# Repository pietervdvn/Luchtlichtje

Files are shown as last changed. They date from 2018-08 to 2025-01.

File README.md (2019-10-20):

# Luchtlichtje

Source code and hardware spec of the ESP8266 driven Air Quality Indicator "Luchtlichtje" (Dutch for 'air light')

A small ESP/Arduino Project, showing lights indicating the air quality, based on data from luftdaten.info

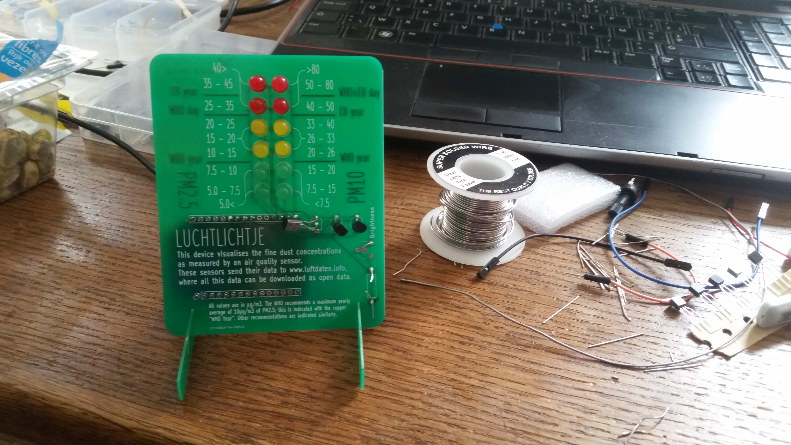
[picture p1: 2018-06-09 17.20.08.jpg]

Moving Pic

## API

Get your sensor data at http://api.luftdaten.info/v1/sensor/7245/

## Bill of Materials

- A Luchtlichtje PCB
- 4 LEDS of each colour (RED, YELLOW, GREEN) of 5mm (or some other colours)
- 3 resistors of around 10ohm (use higher such as 220ohm for less brightness)
- 1 photoresistor of a pretty high resistance, in combination with a 1Mohm resistor*

*If you don't like the brightness settings or have a different photoresistor, you can change the code to have other settings*

## Flashing a Luchtlichtje

- Install platformio
- Open the console
- cd to the desired directory (v0.2/firmware)
- `sudo platformio run --target upload`
- Use `platformio run --target monitor` to see what is happening

## Assembly instructions

- Start with placing the resistors. The resistor 'R1 Different'-resistor (bottom right) takes the 1-mega-ohm resistor
- The other three have 10-ohm resistors (upper and left side).
- Next, place the leds. Be carefull, they have to be oriented correctly: the flattened sides go in the middle. Green leds down, red leds up - just like traffic lights. Solder them neatly and straight.
- Place and solder the header pins on the backside of the board.
- Flash the software on the nodemcu and place it on the backside (see above).
- Gently break the board along the cutlines on the right. If they don't come off, use a knife on the back side of the board.
- These small rectangular break-off pieces can be slided in the main board, to place it on your desk.
- The break-off parts easily fall of the board when lifted. To prevent this, place a piece of wire through the holes in the break-off part and the main board.
- All done! Enjoy your Luchtlichtje.

## Troubleshooting

When booting, the board will test all leds blinking from up to down.
If a led does not blink, check the soldering.
If more then the desired leds burn, some LEDS are soldered in the wrong direction.

If the orange leds start blinking one after another; the board is connecting to the wifi. This will always happen for a few seconds when booting.

If the reds leds are blinking, either luftdaten or your sensor is down. 

## Versions

The first version (v1.0) is dated 2018-05-15
The second version (v2.0) is dated 2018-08-24. Changes are: removal of unused transistors, addition of a brightness sensor, fancier placement of resistors.

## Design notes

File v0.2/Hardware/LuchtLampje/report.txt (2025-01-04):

Info: Backing up file '/home/pietervdvn/git/Luchtlichtje/v0.2/Hardware/LuchtLampje/sym-lib-table' to '/home/pietervdvn/git/Luchtlichtje/v0.2/Hardware/LuchtLampje/rescue-backup/sym-lib-table-2025-01-04-02-21-57'.
Info: Backing up file '/home/pietervdvn/git/Luchtlichtje/v0.2/Hardware/LuchtLampje/LuchtLampje.sch' to '/home/pietervdvn/git/Luchtlichtje/v0.2/Hardware/LuchtLampje/rescue-backup/LuchtLampje-2025-01-04-02-21-57.sch'.
Info: Backing up file '/home/pietervdvn/git/Luchtlichtje/v0.2/Hardware/LuchtLampje/LuchtLampje.kicad_pro' to '/home/pietervdvn/git/Luchtlichtje/v0.2/Hardware/LuchtLampje/rescue-backup/LuchtLampje-2025-01-04-02-21-57.kicad_pro'.
Info: Backing up file '/home/pietervdvn/git/Luchtlichtje/v0.2/Hardware/LuchtLampje/LuchtLampje-cache.lib' to '/home/pietervdvn/git/Luchtlichtje/v0.2/Hardware/LuchtLampje/rescue-backup/LuchtLampje-cache-2025-01-04-02-21-57.lib'.
Info: Backing up file '/home/pietervdvn/git/Luchtlichtje/v0.2/Hardware/LuchtLampje/LuchtLampje-rescue.lib' to '/home/pietervdvn/git/Luchtlichtje/v0.2/Hardware/LuchtLampje/rescue-backup/LuchtLampje-rescue-2025-01-04-02-21-57.lib'.
Info: Backing up file '/home/pietervdvn/git/Luchtlichtje/v0.2/Hardware/LuchtLampje/LuchtLampje-rescue.dcm' to '/home/pietervdvn/git/Luchtlichtje/v0.2/Hardware/LuchtLampje/rescue-backup/LuchtLampje-rescue-2025-01-04-02-21-57.dcm'.
Info: Adding library 'LuchtLampje-rescue', file '${KIPRJMOD}/LuchtLampje-rescue.lib' to project symbol library table.
Symbol LED mapped to symbol library 'LuchtLampje-rescue'.
Symbol LED mapped to symbol library 'LuchtLampje-rescue'.
Symbol LED mapped to symbol library 'LuchtLampje-rescue'.
Symbol LED mapped to symbol library 'LuchtLampje-rescue'.
Symbol LED mapped to symbol library 'LuchtLampje-rescue'.
Symbol R mapped to symbol library 'LuchtLampje-rescue'.
Symbol LED mapped to symbol library 'LuchtLampje-rescue'.
Symbol LED mapped to symbol library 'LuchtLampje-rescue'.
Symbol R mapped to symbol library 'LuchtLampje-rescue'.
Symbol R mapped to symbol library 'LuchtLampje-rescue'.
Symbol LED mapped to symbol library 'LuchtLampje-rescue'.
Symbol LED mapped to symbol library 'LuchtLampje-rescue'.
Symbol LED mapped to symbol library 'LuchtLampje-rescue'.
Symbol LED mapped to symbol library 'LuchtLampje-rescue'.
Symbol LED mapped to symbol library 'LuchtLampje-rescue'.
Symbol CONN_01X15 mapped to symbol library 'LuchtLampje-rescue'.
Symbol CONN_01X15 mapped to symbol library 'LuchtLampje-rescue'.
Symbol R mapped to symbol library 'LuchtLampje-rescue'.
Symbol R_PHOTO mapped to symbol library 'LuchtLampje-rescue'.
Info: Symbol library table mapping complete!
Info: Created project symbol library table.

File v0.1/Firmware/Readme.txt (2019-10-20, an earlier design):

The firmware for version 1.0 has been merged with the firmware for 2.0.

The major difference between both is the addition of brightness-sensor. For a v1.0 board, disable it in the firmware by setting the USE_BRIGHTNESS -macro to false

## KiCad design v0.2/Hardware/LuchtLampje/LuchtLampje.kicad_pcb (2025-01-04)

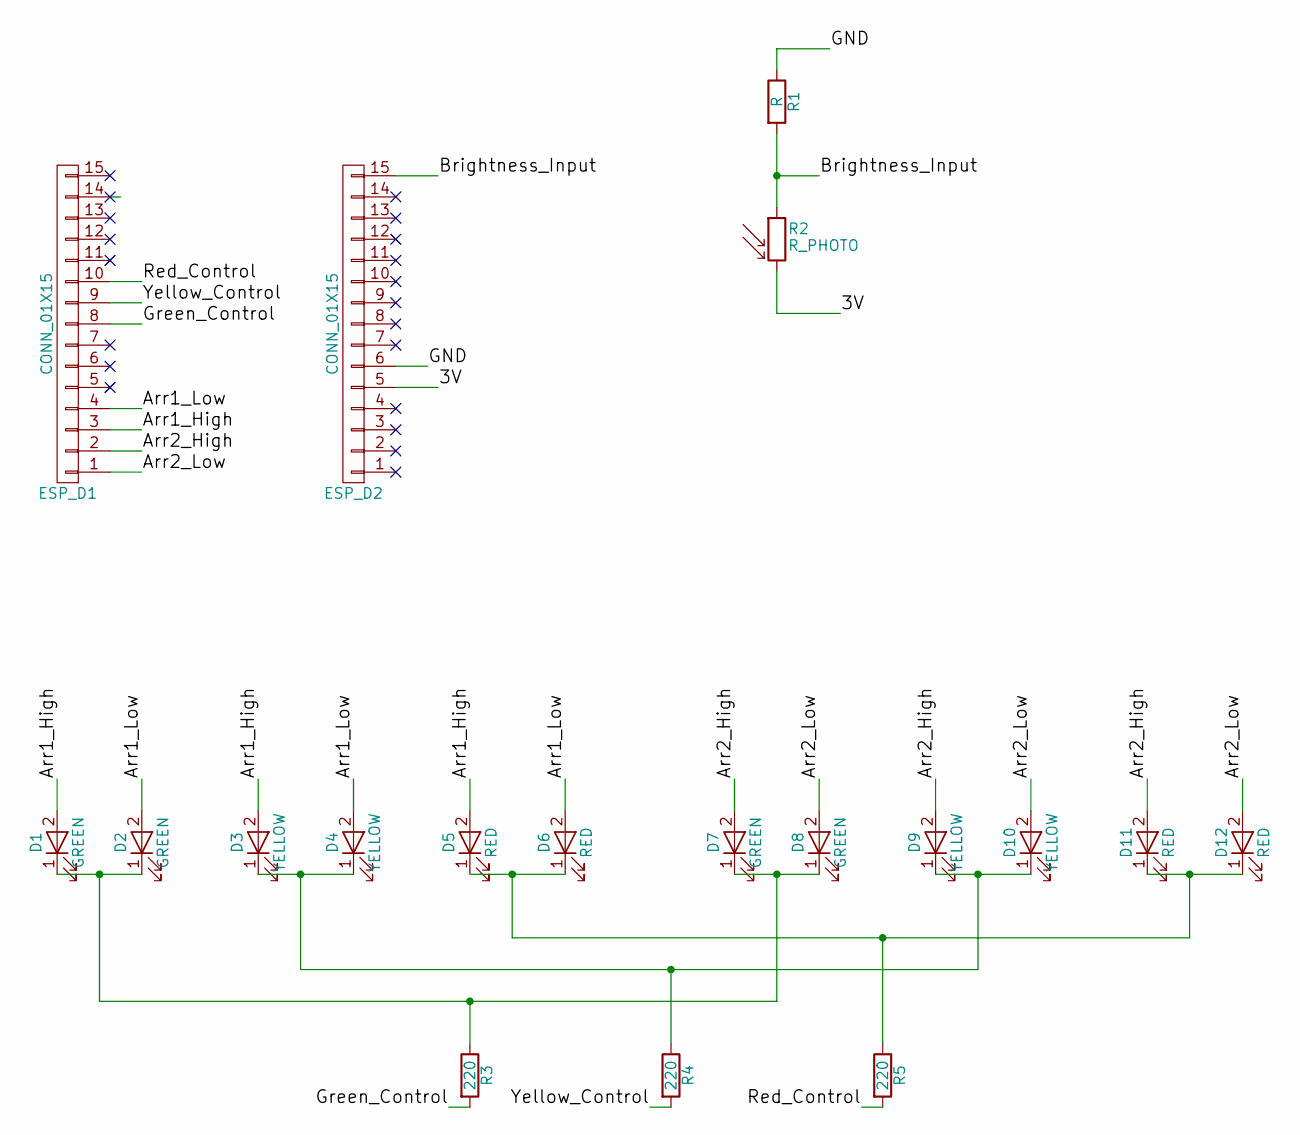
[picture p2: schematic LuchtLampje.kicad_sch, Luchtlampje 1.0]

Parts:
D1, D2, D7, D8: GREEN; LED_D5.0mm
D3, D4, D9, D10: YELLOW; LED_D5.0mm
D5, D6, D11, D12: RED; LED_D5.0mm
ESP_D1, ESP_D2: CONN_01X15; Socket_Strip_Straight_1x15_Pitch2.54mm
R1: R; R_Axial_DIN0411_L9.9mm_D3.6mm_P12.70mm_Horizontal
R2: R_PHOTO; R1
R3, R4, R5: 220; R_Axial_DIN0411_L9.9mm_D3.6mm_P12.70mm_Horizontal

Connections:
/3V: ESP_D2.5, R2.2
/Arr1_High: D1.2 (A), D3.2 (A), D5.2 (A), ESP_D1.3
/Arr1_Low: D2.2 (A), D4.2 (A), D6.2 (A), ESP_D1.4
/Arr2_High: D7.2 (A), D9.2 (A), D11.2 (A), ESP_D1.2
/Arr2_Low: D8.2 (A), D10.2 (A), D12.2 (A), ESP_D1.1
/Brightness_Input: ESP_D2.15, R1.2, R2.1
/GND: ESP_D2.6, R1.1
/Green_Control: ESP_D1.8, R3.2
/Red_Control: ESP_D1.10, R5.2
/Yellow_Control: ESP_D1.9, R4.2
unnamed: D1.1 (K), D2.1 (K), D7.1 (K), D8.1 (K), R3.1
unnamed: D3.1 (K), D4.1 (K), D9.1 (K), D10.1 (K), R4.1
unnamed: D5.1 (K), D6.1 (K), D11.1 (K), D12.1 (K), R5.1

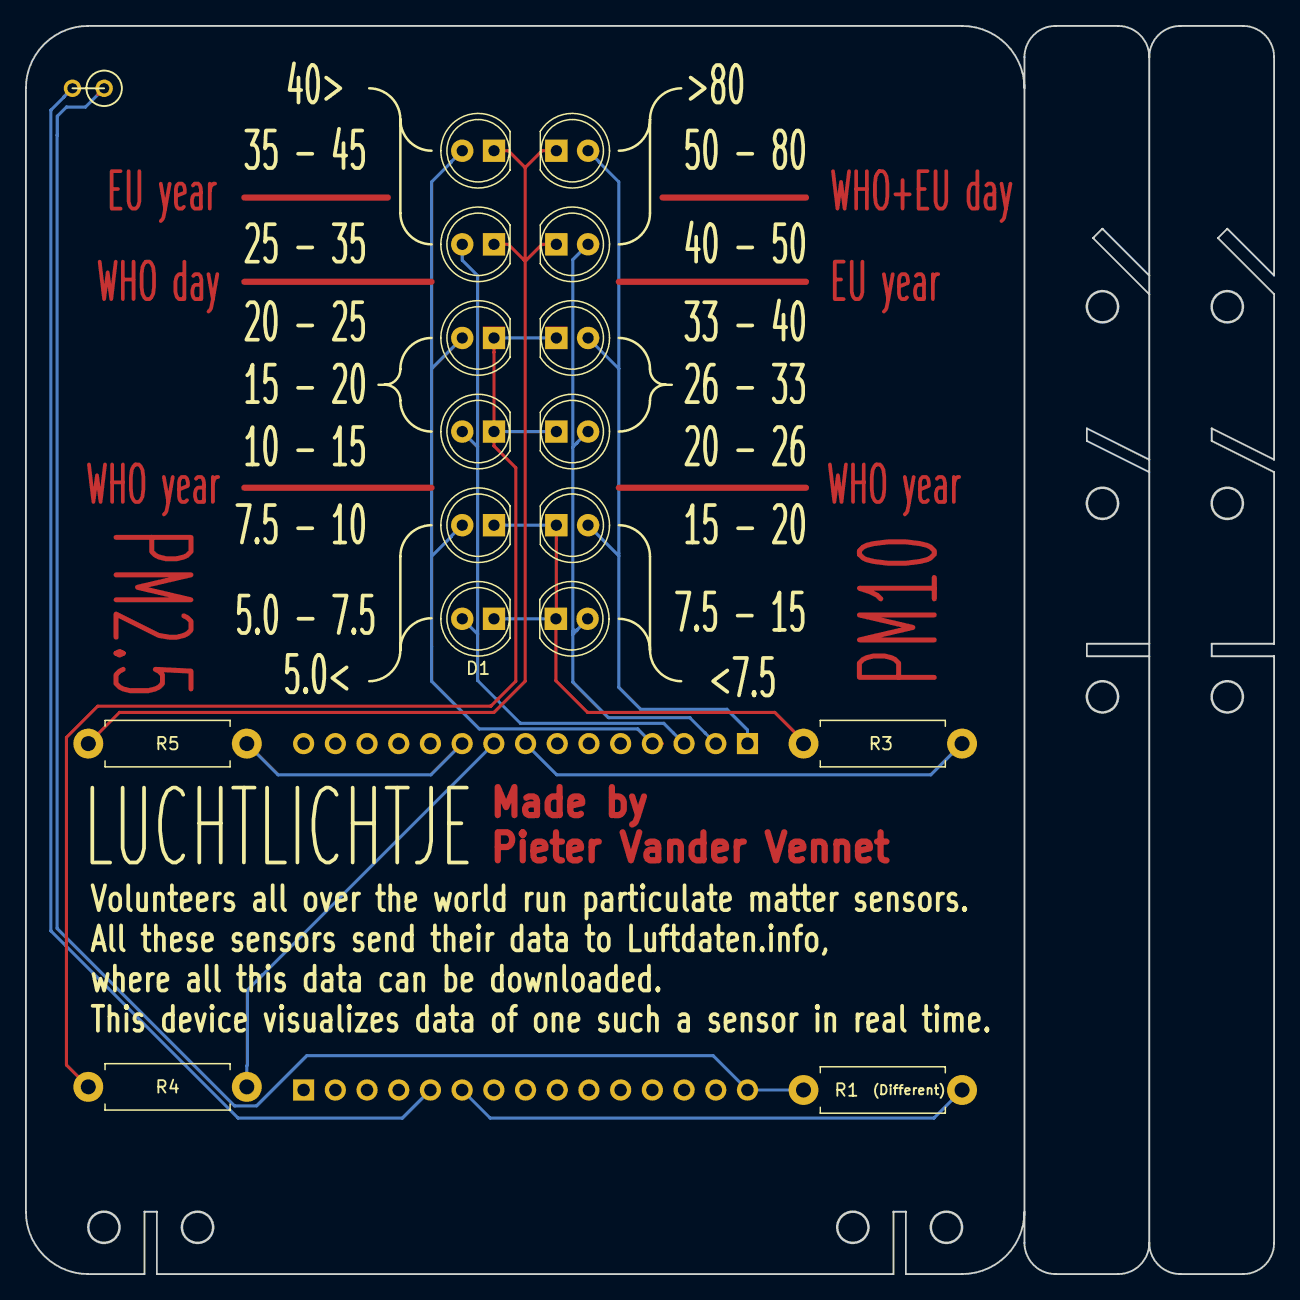
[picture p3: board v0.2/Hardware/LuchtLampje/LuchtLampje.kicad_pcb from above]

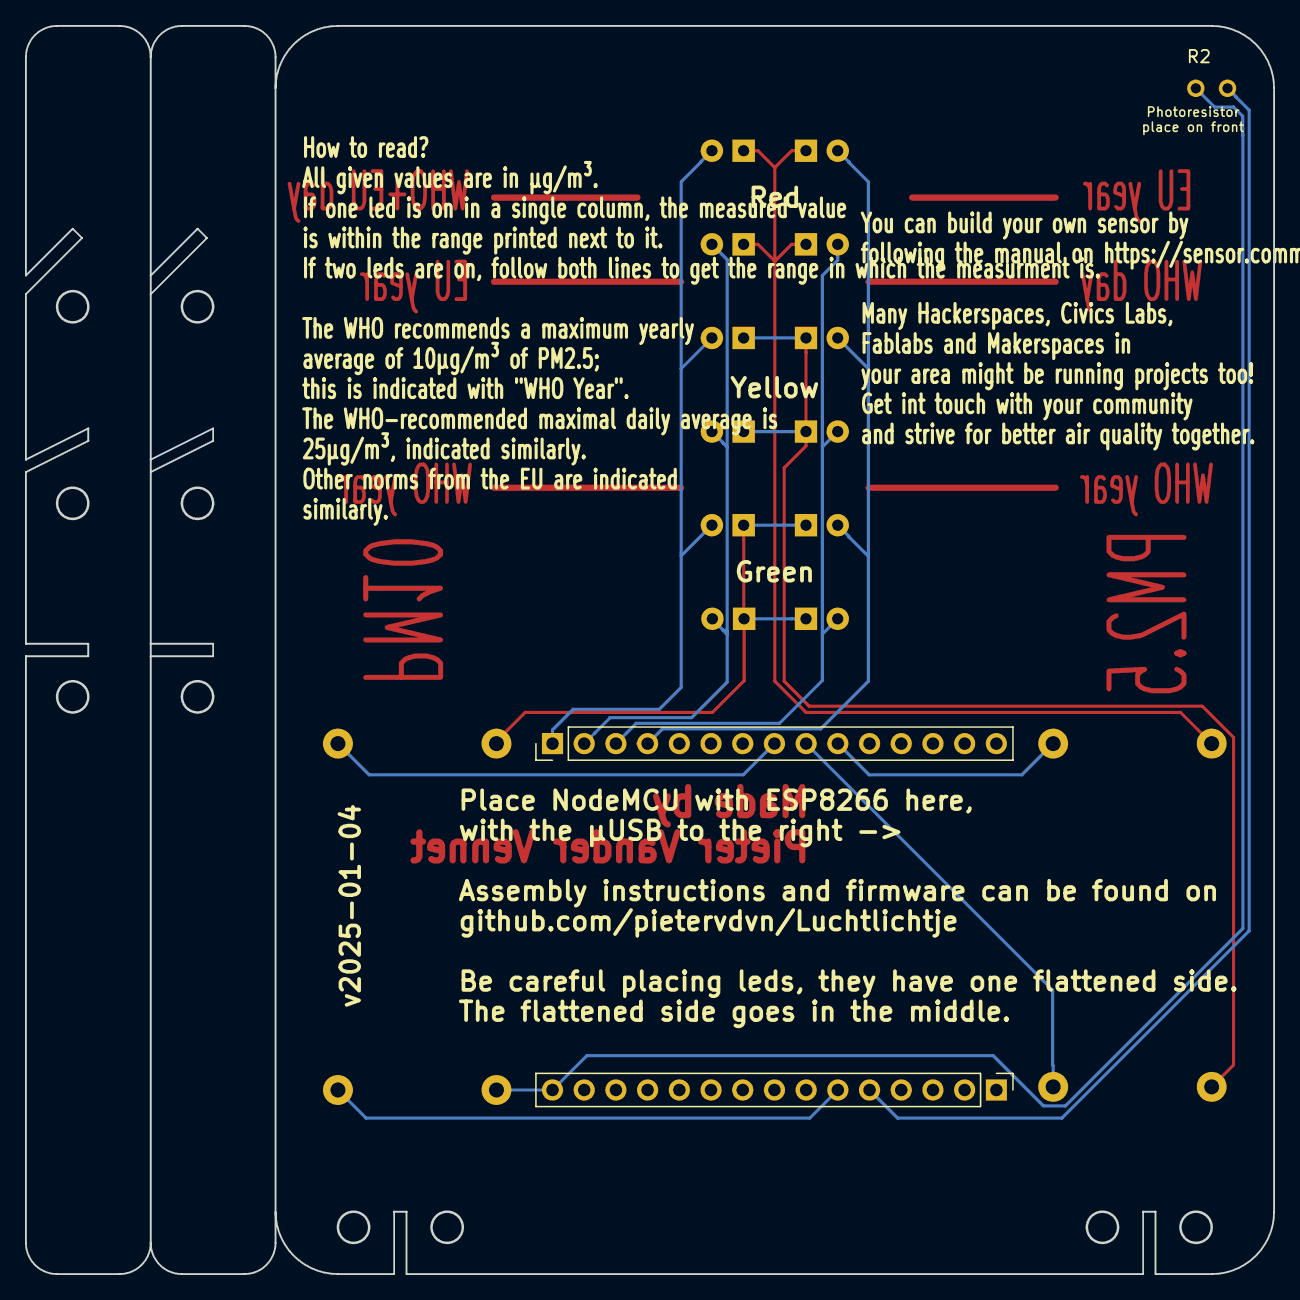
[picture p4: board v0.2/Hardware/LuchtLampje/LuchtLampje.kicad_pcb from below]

Board: 2 copper layers, 100.0 x 100.0 mm, 19 parts (2 on the bottom side), 13 nets.

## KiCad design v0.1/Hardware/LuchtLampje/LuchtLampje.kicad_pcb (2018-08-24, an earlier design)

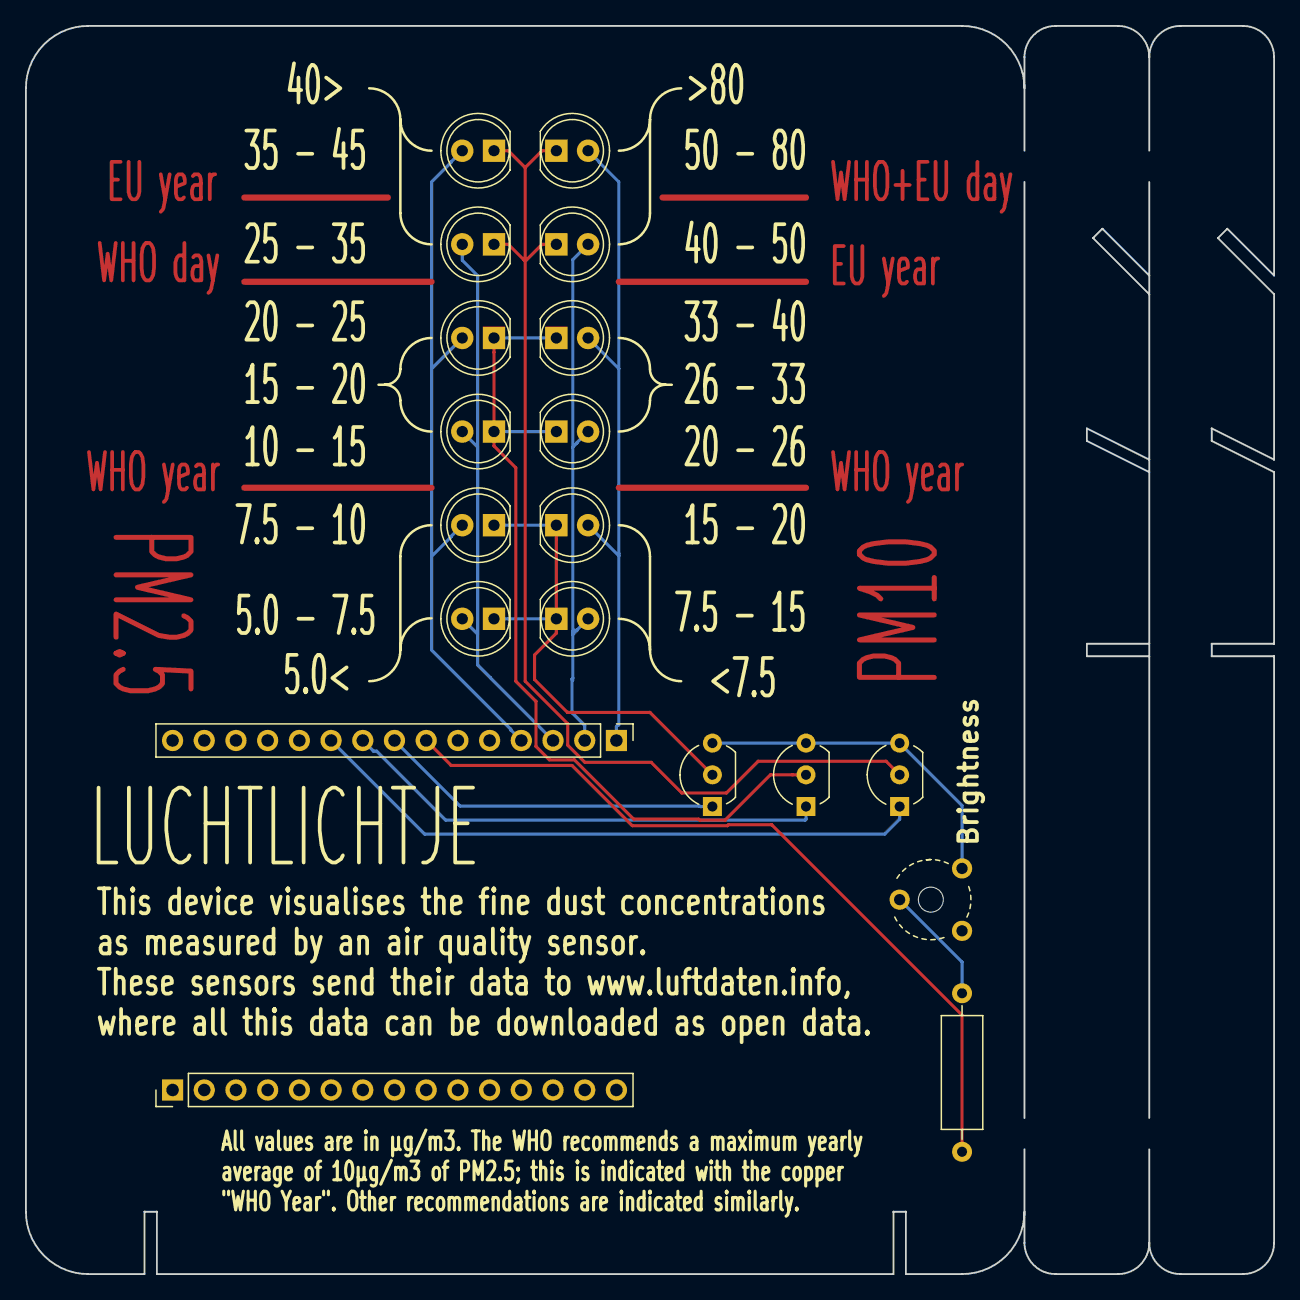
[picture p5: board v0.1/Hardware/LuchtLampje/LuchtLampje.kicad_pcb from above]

Board: 2 copper layers, 100.0 x 100.0 mm, 19 parts (0 on the bottom side), 13 nets.

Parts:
D2, D7, D8: GREEN; LED_D5.0mm
D3, D4, D9, D10: YELLOW; LED_D5.0mm
D5, D6, D11, D12: RED; LED_D5.0mm
ESP_D1, ESP_D2: CONN_01X15; Socket_Strip_Straight_1x15_Pitch2.54mm
Green: GREEN; LED_D5.0mm
Q1, Q2, Q3: NPN_Green; TO-92_Inline_Wide
R1: 1K; R_Axial_DIN0309_L9.0mm_D3.2mm_P12.70mm_Horizontal
RV1: POT 10K; Potentiometer_Trimmer_Piher_PT-6v_Horizontal_MountLS

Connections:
/Arr1_High: D3.2, D5.2, ESP_D1.3, Green.2
/Arr1_Low: D2.2, D4.2, D6.2, ESP_D1.4
/Arr2_High: D7.2, D9.2, D11.2, ESP_D1.2
/Arr2_Low: D8.2, D10.2, D12.2, ESP_D1.1
/GND: ESP_D1.7, R1.2
/Green_Control: ESP_D1.8, Q1.1
/Red_Control: ESP_D1.10, Q3.1
/Yellow_Control: ESP_D1.9, Q2.1
unnamed: D2.1, D7.1, D8.1, Green.1, Q1.2
unnamed: D3.1, D4.1, D9.1, D10.1, Q2.2
unnamed: D5.1, D6.1, D11.1, D12.1, Q3.2
unnamed: Q1.3, Q2.3, Q3.3, RV1.1
unnamed: R1.1, RV1.2

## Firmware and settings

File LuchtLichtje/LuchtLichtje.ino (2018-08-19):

#include <ArduinoJson.h>
#include <ESP8266WiFi.h>
#include <ESP8266WiFiMulti.h>
#include <ESP8266HTTPClient.h>
#include <Arduino.h>

/** 
 * Kindoff working working 2018-08-19
 * Use Arduino IDE
 * ESP8266 by ESP8266 Community v. 2.3.0
 * Board: NodeMCU (12E)
 * CPU Freq: 80Mhz
 * Flash size: 4M (3M SPiffs)
 * Upload speed: 115200
 */

// WIFI DETAILS


// TYPE YOUR WIFI SSID HERE:
#define WIFIAP "fri3d-legacy"
// TYPE YOUR WIFI PASSWORD HERE
#define WIFIPASS "fri3dcamp"
// SEARCH A SENSOR ON luftdaten.info
// CLICK IT
// LOOK FOR SENSOR ID IN THE TABLE APPEARING RIGHT
// CHANGE IT ON THE END (do not remove the trailing slash)
#define SENSOR "http://api.luftdaten.info/v1/sensor/12988/"





// Time between two updates, in minutes
#define UPDATE_TIMEOUT 15
// Time in seconds between retries when failed. Should be a multiple of 4
#define RETRY_TIMEOUT 12

// ---------------------------------------- PIN DEFINTIONS FOR LEDS ------------------------------------------

#define RIGHTH D0
#define RIGHTL D1

#define LEFTH D3
#define LEFTL D2

#define GREEN D5
#define YELLOW D6
#define RED D7

#define LEFT 0
#define RIGHT 1

#define posPinL 4
// should be HIGH to work
int posPins[posPinL] = {LEFTH, LEFTL, RIGHTH, RIGHTL}; 
#define negPinL 3
// should be low to work
int negPins[negPinL] = {RED, YELLOW, GREEN}; 
// ---------------------- WIFI STUFF

ESP8266WiFiMulti WiFiMulti;

// -------------------------- Status tracking

#define CONNECTING 0
#define UP_TO_DATE 1

#define NOT_CONNECTED 2
#define HTTP_ERR 3
#define PARSE_ERR 4

// Color encodings
#define EXTREMELY_GOOD 0 // Double green
#define VERY_GOOD 1 // single, lowest green
#define GOOD 2 // single, highest green

#define LOW_AVG 3 // lowest yellow
#define AVG 4 // TWO_YELLOWS
#define HIGH_AVG 5 // Highest yellow

#define BAD 6 // lowest red
#define VERY_BAD 7// highest red
#define EXTREMELY_BAD 8// two red

#define OFF 9

#define USE_SERIAL Serial

/*
 * As per http://www.who.int/mediacentre/factsheets/fs313/en/
 * and per http://ec.europa.eu/environment/air/quality/standards.htm
 * WHO allows a daily mean of 25µg, and a yearly mean of 10µg (PM2.5)
 * EU allows a yearly mean of 25µg (PM2.5)
 * 
 * IN practice: seldom over 50
 * 
 * WHO allows a daily mean of 50µg and a yearly mean of 20µg (PM10)
 * EU allows a daily mean of 50µg, and a yearly mean of 40µg (PM10)
 * 
 * The color coding: over the yearly WHO norm -> yellow; over the yearly EU-norm -> red

 */

float* barema25 = new float[9] {0, /*GOOD:*/5,  7.5, 10, /*AVG*/ 15,   20,   25,/*BAD*/ 35, 45};
float* barema10 = new float[9] {0, /*GOOD:*/7.5, 15, 20, /*AVG*/ 26.6, 33.3, 40,/*BAD*/ 50, 80};



// ------------------------------------------- MAIN PROGRAM --------------------------------


void setup() {
  WiFi.mode(WIFI_STA);
  WiFiMulti.addAP(WIFIAP, WIFIPASS);


 USE_SERIAL.begin(115200);

  initLeds(); 
  startAnimation();
}


void loop() {
  USE_SERIAL.println("Updating");
  float pm10, pm25;
  int status = NOT_CONNECTED;
  int retries = 8;
  while(status !=  UP_TO_DATE && retries > 0){
    USE_SERIAL.printf("Attempting update. %d retries left\n", retries);
    status = update(&pm10, &pm25);
    if(status != UP_TO_DATE){
      showError(status, 8-retries);
      delay(500);
    }
    retries --;
  }

  if(status != UP_TO_DATE){
    USE_SERIAL.write("Update failed\n");
    for(int i = 0; i < RETRY_TIMEOUT; i++){
      showError(status,i);
      delay(1000);
      USE_SERIAL.printf("Retrying in %d\n", RETRY_TIMEOUT - i);
    }    return;
  }

  USE_SERIAL.printf("PM2.5: %d; PM10: %d\n",(int) pm25,(int) pm10);
  // We are up to date. Lets show the bars!
  // We draw one of them, show it for 5ms and hide it again. Then, we show the other bar.
  // The inner loop does this 200 times (one second)

  allLedsOff();
 int m = 0; 
 for(int m = 0; m < UPDATE_TIMEOUT; m++){ 
    for(int s = 0; s < 60; s++){
      if(s % 15 == 0){
        USE_SERIAL.printf("Next update in %d:%2d\n", UPDATE_TIMEOUT - 1 - m, 60 - s);
      }
      for(int ms = 0; ms < 100; ms++){
        allLedsOff();
        showEncoding(mapState(pm25, barema25), LEFT);
        delay(5);
        allLedsOff();
        showEncoding(mapState(pm10, barema10), RIGHT);
        delay(5);
      }
    }
  }
  // Power both rails while updating...
  digitalWrite(LEFTH, HIGH);
  digitalWrite(LEFTL, HIGH);
  
}






// ------------------------------------------------------------- UPDATE DATA -------------------------------------------------


int update(float* pm10, float* pm25){
  if(WiFiMulti.run() != WL_CONNECTED) {
    USE_SERIAL.print("[HTTP] wifi not connected...\n");
    return NOT_CONNECTED;
  }
  
  HTTPClient http;

  USE_SERIAL.print("[HTTP] begin...\n");
  // configure server and sho
  http.begin(SENSOR);
   
  USE_SERIAL.print("[HTTP] GET...\n");
  // start connection and send HTTP header
  int httpCode = http.GET();
  USE_SERIAL.printf("[HTTP] Get Done \n");
  USE_SERIAL.printf("[HTTP] Get code is %d\n", httpCode);
  // httpCode will be negative on error
  if(httpCode <= 0) {
    USE_SERIAL.printf("[HTTP] GET... failed, error: %s\n", http.errorToString(httpCode).c_str());
    http.end();
    return HTTP_ERR;
  }

  // HTTP header has been send and Server response header has been handled
  USE_SERIAL.printf("[HTTP] GET... code: %d\n", httpCode);

  // file not found at server or other problem
  if(httpCode != HTTP_CODE_OK) {
    USE_SERIAL.printf("[HTTP] GET... returned error status code: %d\n", httpCode);
    http.end();
    return HTTP_ERR;
  }
  
  String payload = http.getString();
  USE_SERIAL.println("Got the payload");
  StaticJsonBuffer<3000> jsonBuffer;
  JsonArray& root = jsonBuffer.parseArray(payload);
  if (!root[0].success()) {
    USE_SERIAL.println("parseObject() failed");
    USE_SERIAL.println(payload);
    return PARSE_ERR;
  }

  *pm10 = (root[0]["sensordatavalues"][0]["value"].as<float>() + root[1]["sensordatavalues"][0]["value"].as<float>())/2;
  *pm25 = (root[0]["sensordatavalues"][1]["value"].as<float>() + root[1]["sensordatavalues"][1]["value"].as<float>())/2;

  http.end();
  return UP_TO_DATE;
}

// Blinks the leds in an error-indicating sequence
// Takes 3 seconds to complete
void showError(int status, int phase){

  allLedsOff();
  int baseLed = 4;

  if(status == NOT_CONNECTED){
    baseLed = 2;
  }
  if(status == HTTP_ERR){
    baseLed = 0;
  }
  if(status == PARSE_ERR){
    baseLed = 1;
  }

  switch(phase % 4){
    case(0): setLed(true, baseLed, LEFT);break;
    case(1): setLed(true, baseLed, RIGHT);break;
    case(2): setLed(true, baseLed+1, RIGHT);break;
    case(3): setLed(true, baseLed+1, LEFT);break;
    
  }
}


// ----------------------------------------- LED CONTROL --------------------------------------------

/**
 * This function calculates the state of the PM, given the barema
 */
int mapState(float value, float* barema){
  for(int state = 1; state < OFF; state++){
    if(barema[state] > value){
       return state - 1;
    }
  }
  return EXTREMELY_BAD;
}



void showEncoding(int encoding, int series){
  switch(encoding){
    case(EXTREMELY_GOOD): setLed(true, 4, series); setLed(true, 5, series); break;
    case(VERY_GOOD): setLed(true, 5, series); break;
    case(GOOD): setLed(true, 4, series); break;
    
    case(LOW_AVG): setLed(true, 3, series); break;
    case(AVG): setLed(true, 3, series); setLed(true, 2, series); break;
    case(HIGH_AVG): setLed(true, 2, series); break;
    
    case(BAD): setLed(true, 1, series); break;
    case(VERY_BAD): setLed(true, 0, series); break;
    case(EXTREMELY_BAD): setLed(true, 0, series); setLed(true, 1, series); break;
  }
}


// ----------------------------------------- LED CONTROL --------------------------------------------

/** Number: the number of the led, with 0 being red, 2 being yellow and 4 being green
 *  Series: 0 = left; 1 = right
 */
void setLed(boolean status, int number, int series){
  series = (number % 2) == 0 ?  posPins[series*2] : posPins[series*2 + 1];
  int pin = negPins[number/2];

  digitalWrite(pin, status ? LOW : HIGH);
  digitalWrite(series, status ? HIGH : LOW); 
}

void initLeds(){
  for(int i = 0; i < negPinL; i++){
    pinMode(negPins[i], OUTPUT);
  }
  for(int i = 0; i < posPinL; i++){
    pinMode(posPins[i], OUTPUT);
  }
  allLedsOff();
}

void allLedsOff(){
  for(int i = 0; i < 6; i++){
    setLed(false, i, LEFT);
    setLed(false, i, RIGHT);
  }
}

void startAnimation(){
  for(int i = 0; i < 6; i ++){
    setLed(true, i,LEFT);
    setLed(true, i,RIGHT);
    delay(750);
    setLed(false, i,LEFT);
    setLed(false, i,RIGHT);
  }
}

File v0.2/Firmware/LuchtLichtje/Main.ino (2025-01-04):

#include <ESP8266WiFi.h>
#include <ESP8266mDNS.h>
// #include <ESP8266HTTPClient.h>

#include <math.h>
#include <ArduinoJson.h>

#include <EEPROM.h>


String Header;
// Set web server port number to 80
WiFiServer server(80);

String wifi_ssid = "";
String wifi_password = "";
String wifi_ssid_2 = "";
String wifi_password_2 = "";
String hostname = "luchtlichtje";

int sensor_id = 59878;

int status = 0 /*NOT_YET_LOADED*/;

#define ACCESS_POINT_MODE 1
int mode = 0;

void writeStringToEEPROM(int addrOffset, const String &strToWrite)
 {
    byte len = strToWrite.length();
    EEPROM.write(addrOffset, len);
    for (int i = 0; i < len; i++)
    {
        EEPROM.write(addrOffset + 1 + i, strToWrite[i]);
    }
    EEPROM.commit();
    Serial.print("Written string to eeprom: index: ");
    Serial.print(addrOffset);
    Serial.print("; length: ");
    Serial.print(len);
 }
 
  void writeIntToEEProm(int addrOffset, int value)
  {
    byte len = 4;
    for(int i = 0; i < len; i++){
        EEPROM.write(addrOffset + i, value % 256);
        value = value / 256;
    }
    EEPROM.commit();
  }
  
    int readIntFromEEProm(int addrOffset)
    {
      byte len = 4;
      int value = 0;
      for(int i = 3; i >= 0; i--){
          value = value * 256;
          value += EEPROM.read(addrOffset + i);
      }
      return value;
    }
    
  
 
 String readStringFromEEPROM(int addrOffset) {
   int newStrLen = EEPROM.read(addrOffset);
   char data[newStrLen + 1];
   for (int i = 0; i < newStrLen; i++)
   {
     data[i] = EEPROM.read(addrOffset + 1 + i);
   }
   data[newStrLen] = '\0';
   return String(data);
 }



#define WIFI_SSID_LOCATION 10
#define WIFI_PASSWORD_LOCATION 265
#define HOSTNAME_LOCATION 522
#define WIFI_SSID_2_LOCATION 778
#define WIFI_PASSWORD_2_LOCATION 1034
#define SENSOR_ID_LOCATION 1290

void setup() {
    Serial.begin(115200);
    initLeds();
    startAnimation();


    /*
    * We save 5 strings of max 255 chars:
    * wifi_ssid (*2)
    * wifi_password (*2)
    * hostname
    *
    * Furthermore, we save a telltale-string at location 0 namely "traffic_light" in order to see if things are initialized already
    * At last, we save one extra int for the luftdaten-id
    */
    EEPROM.begin(256*5 + 10 + 4);
    delay(150);
    String telltale = readStringFromEEPROM(1);
    Serial.println("Telltale is:");
    Serial.println(telltale);
    if(telltale.length() == 7 && telltale.equals("rainbow")){
      sensor_id = readIntFromEEProm(SENSOR_ID_LOCATION);
      Serial.printf("This device has run the Luchtlichtje-light code before. Loaded sensor ID: %d\n", sensor_id);

    }else{
      Serial.println("Initializing EEPROM");
      writeStringToEEPROM(WIFI_SSID_LOCATION, "");
      writeStringToEEPROM(WIFI_PASSWORD_LOCATION, "");
      writeStringToEEPROM(WIFI_SSID_2_LOCATION, "");
      writeStringToEEPROM(WIFI_PASSWORD_2_LOCATION, "");
      writeStringToEEPROM(HOSTNAME_LOCATION, "luchtlichtje");
      writeIntToEEProm(SENSOR_ID_LOCATION, 0);

      writeStringToEEPROM(1, "rainbow");
      Serial.println("Init done");
    }
    setupWifi();
      // Set time via NTP, as required for x.509 validation
    if(WiFi.status() == WL_CONNECTED){
    configTime(0, 0, "pool.ntp.org", "time.nist.gov");
    time_t now = time(nullptr);
    while (now < 1676426912) { // a random timestamp from the past
        Serial.println("Waiting for time to set correctly...");
        delay(500);
        Serial.print(".");
        now = time(nullptr);
    }
    struct tm timeinfo;
    gmtime_r(&now, &timeinfo);
    Serial.print("Current time: ");
    Serial.print(asctime(&timeinfo));
    }

}

bool accessPointStarted = false;
void setupAccessPoint(){
    if(accessPointStarted){
        return;
    }
    accessPointStarted = true;
    mode = ACCESS_POINT_MODE;
    hostname = "luchtlichtje";
    WiFi.softAP(hostname+"_setup");
    server.begin();
    Serial.println("AP setup done. Connect on 192.168.4.1");
}


void attemptToConnectWith(String ssid, String password, int secondsToWait){
    if(ssid.length() == 0){
        return;
    }
    Serial.print("Attempting to connect to wifi ");
    Serial.println(ssid);
    WiFi.begin(ssid,password);
    int count = 10 * 60; //Attempt to connect for one minute
    int maxCount = count;
    unsigned long time = millis();
    unsigned long seconds = time / 1000;

    while (WiFi.status() != WL_CONNECTED && count >= 0) {
        delay(100);
        animate(seconds);
        count --;
        Serial.print(".");
        if(count % 100 == 0){
            Serial.print("\nAttempting to connect with ");
            Serial.print(wifi_ssid);
            Serial.print(" ");
            Serial.print(password);
            Serial.print(" (");
            Serial.print(count / 10);
            Serial.println(" seconds left)");
        }
    }
}

// Connect to Wi-Fi network with SSID and password
void setupWifi(){

    
    wifi_ssid = readStringFromEEPROM(WIFI_SSID_LOCATION);
    hostname = readStringFromEEPROM(HOSTNAME_LOCATION);
    WiFi.hostname(hostname);
    if(wifi_ssid != ""){
        wifi_password = readStringFromEEPROM(WIFI_PASSWORD_LOCATION);

        Serial.println("Trying primary wifi network: " + wifi_ssid);
        attemptToConnectWith(wifi_ssid, wifi_password, 20);
    }

    wifi_ssid_2 = readStringFromEEPROM(WIFI_SSID_2_LOCATION);
    if(wifi_ssid != "" &&  WiFi.status() != WL_CONNECTED){

        Serial.println("Trying secondary wifi network: " + wifi_ssid_2);
        wifi_password_2 = readStringFromEEPROM(WIFI_PASSWORD_2_LOCATION);
        attemptToConnectWith(wifi_ssid_2, wifi_password_2, 20);
    }

    if(WiFi.status() != WL_CONNECTED){
        // We reached a timeout
        Serial.println("Waiting for wifi connection: timeout. Using AP-mode");
        setupAccessPoint();
        return;
    }

  // Print local IP address and start web server
  Serial.println("");
  Serial.println("WiFi connected.");
  mode = 0;
  
  Serial.println("IP address: ");
  Serial.println(WiFi.localIP());
  
  AdvertiseServices();
  
  server.begin();

}


void loop(){
    unsigned long time = millis();
    unsigned long seconds = time / 1000;

    if(mode == ACCESS_POINT_MODE && (millis() / 1000) % 120 == 0){
        setupWifi();
        status = 5 /*AP_SETUP_ERR*/;
    }else{
        update_pm(seconds);
    }
    animate(seconds);
    handleClient(server.available());   // Listen for incoming clients
    MDNS.update();
}


void AdvertiseServices() {
   
   if (MDNS.begin(hostname))
   {
     // Add service to MDNS-SD
     MDNS.addService("http", "tcp", 80);
     MDNS.update(); 
     Serial.println("Local domain registered!");
   }
   
 }
 

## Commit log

2018-08-19 Temp workspace
    [LuchtlichtjeHW2.kicad_pcb, LuchtlichtjeHW2.sch, _saved_LuchtlichtjeHW2.sch]
2018-08-19 Firmware that should be working if all soldering is correct
    [LuchtLichtje.ino]
2018-08-24 Hardware v2.0
    [LuchtLampje-B.Adhes.gbr, LuchtLampje-B.CrtYd.gbr, LuchtLampje-B.Cu.gbr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]
2018-09-17 Fixed small typographic issues
    [LuchtLampje.kicad_pcb]
2019-10-20 Add support for HTTPS, point the device to the new endpoint
2020-03-08 Removed fingerprint, use more insecure HTTPS (the S in IOT stands for Security)
2025-01-04 Update firmware
    [LuchtLampje-2022-10-19-20-25-00.sch, LuchtLampje-2025-01-04-02-21-57.sch, LuchtLampje.kicad_pcb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]
2025-01-04 Improve landing page
2025-01-04 Small changes
    [LuchtLampje.kicad_pcb]
